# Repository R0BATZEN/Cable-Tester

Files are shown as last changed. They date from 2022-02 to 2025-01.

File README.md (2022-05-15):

# Cable Tester
Inspired by [brodafins](https://www.youtube.com/channel/UCYWdkH3cT7uKhssbFg7uHtw) cable tester I decided to add my own twist to it and make a modified version.

If you would like to check out the original project you should watch his [youtube video](https://www.youtube.com/watch?v=r3Qzw2hiL2Y) and see how he built his unit.
His code can be found in the `brodafin` folder of this repository.

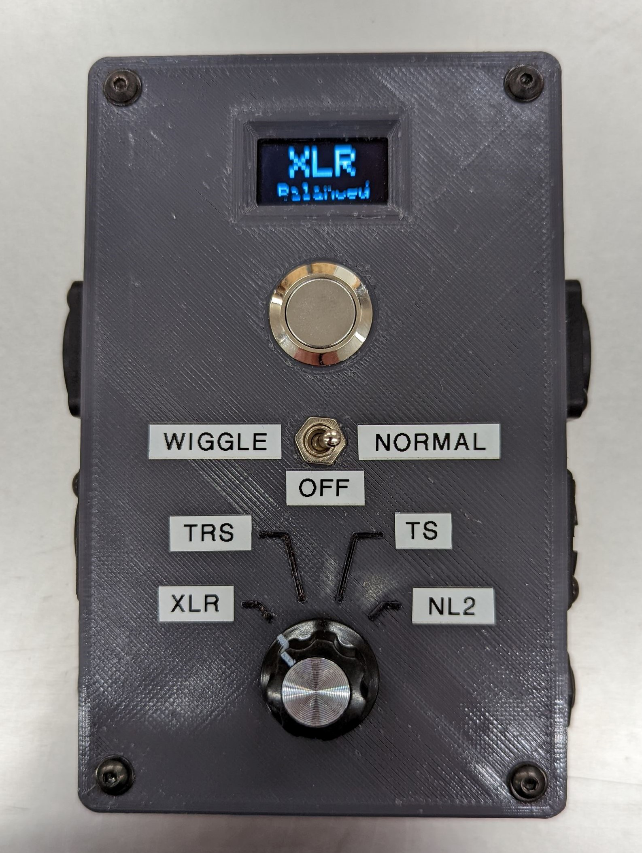
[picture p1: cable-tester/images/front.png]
||||
|-|-|-|
|Front view|Input Side|Output Side|

Besides XLR and 1/4" cables I also use SpeakOn (PA speaker) Cables.
So I added the option to also test those cables (NL2 and NL4 only, I don't use NL8).

## Circuit Design
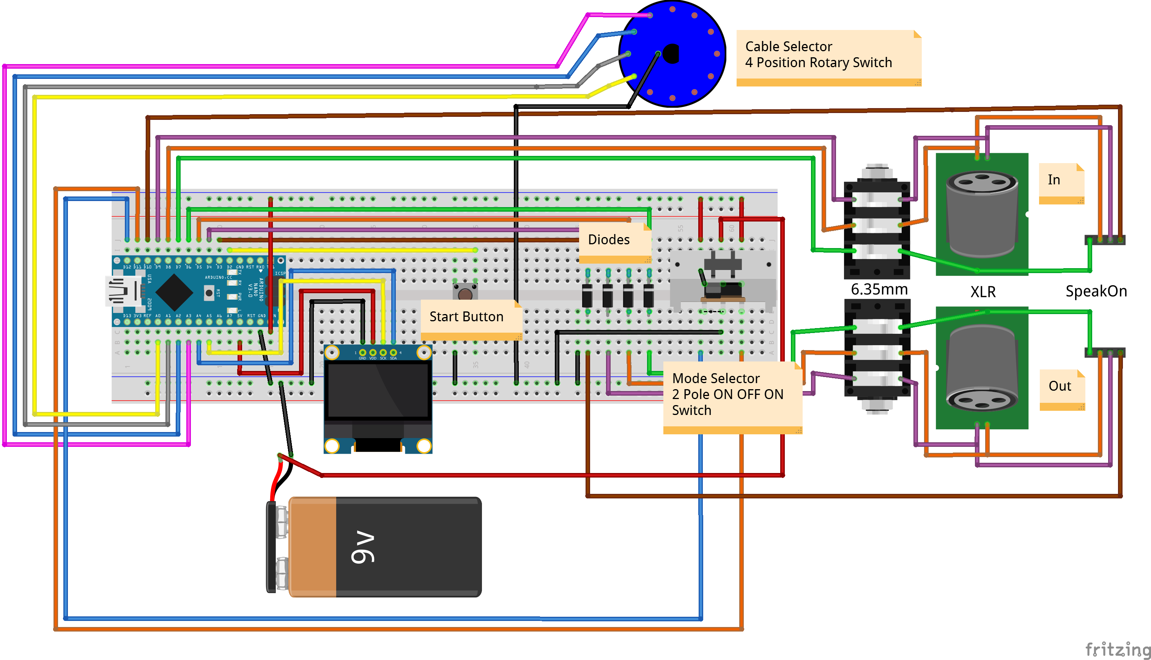
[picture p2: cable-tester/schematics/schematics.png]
schematic

Take a look at the [fritzing file](cable-tester/schematics/schematics.fzz) if you need more details.

## 3D Printed Case
Feel free to download and print my case. Just make sure that your inputs / buttons match mine so that the holes will fit.
In case you want to modify it before printing, I have included my source files.

## Installing the Code
You should be able to just download my source code and flash it to your Arduino (Nano).
If you would like to use different pins for each in/output, the corresponding variables are all at the top of the file.

## Using the Tester
- First decide which mode (wiggle or normal) you would like to use. Flip the switch accordingly and wait ~2 seconds for everything to start up.
- Then connect your cable and select to proper setting using the rotary switch.
- After pressing the start button you will get your results. Either after the "wiggle period" is over or directly after testing.
- First a brief `FAIL` or `PASS` message will appear, after which the detailed test report will be displayed until you press the start button again.
- As an example, here's what a `passing` XLR cable will show:

| |2|3|1|/|
|-|-|-|-|-|
|2|X|O|O|O|
|3|O|X|O|O|
|1|O|O|X|O|
|/|O|O|O|O|

- The rows correspond to each pin on the output and the columns mark the inputs on the other side of the device.
`X` denotes a connection between the two pins and `O` means no connection.
- Take a look at my [cheat sheet](cable-tester/cheat_sheets/cheat_sheet.md) to see how each cable is expected to be wired up.

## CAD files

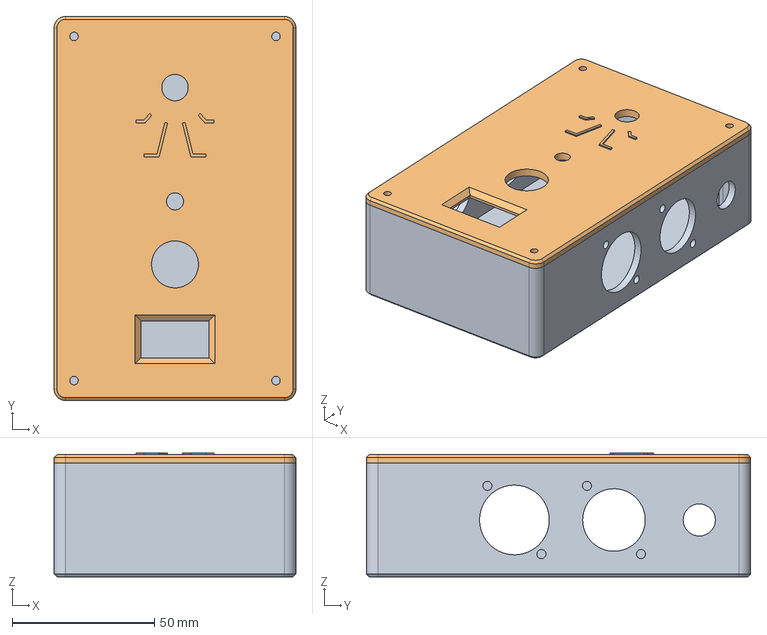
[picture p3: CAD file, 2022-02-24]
cable-tester/3d files/CableTester.step
85.0 x 135.0 x 43.5 mm

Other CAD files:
cable-tester/3d files/CableTester.3mf
cable-tester/3d files/CableTester.f3d

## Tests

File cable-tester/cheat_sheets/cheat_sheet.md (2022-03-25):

# Pins on each cable
And how they are connected to each other in this tester:

|XLR|TRS|TS|SpeakOn|
|-|-|-|-|
|2|T|T|1+|
|3|R|S|1-|
|1|S|S|2+|
|/|/|/|2-|

# Expected test results

## XLR (Balanced)

| |2|3|1|/|
|-|-|-|-|-|
|2|X|O|O|O|
|3|O|X|O|O|
|1|O|O|X|O|
|/|O|O|O|O|

## 1/4" TRS (Stereo / Balanced)

| |T|R|S|/|
|-|-|-|-|-|
|T|X|O|O|O|
|R|O|X|O|O|
|S|O|O|X|O|
|/|O|O|O|O|

## 1/4" TS (Mono / Unbalanced)

| |T|R|S|/|
|-|-|-|-|-|
|T|X|O|O|O|
|R|O|X|X|O|
|S|O|X|X|O|
|/|O|O|O|O|

## SpeakOn (NL2)

| |1+|1-|/|/|
|-|-|-|-|-|
|1+|X|O|O|O|
|1-|O|X|O|O|
|/|O|O|O|O|
|/|O|O|O|O|

## SpeakOn (NL4)

| |1+|1-|2+|2-|
|-|-|-|-|-|
|1+|X|O|O|O|
|1-|O|X|O|O|
|2+|O|O|X|O|
|2-|O|O|O|X|

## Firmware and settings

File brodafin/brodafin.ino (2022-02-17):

//Musicians Cable Tester (SCT)  20210822 by Brodafin
#include <SPI.h>
#include <Wire.h>
#include <Adafruit_GFX.h>
#include <Adafruit_SSD1306.h>
#define OLED_RESET 4
Adafruit_SSD1306 display(OLED_RESET);
int Pass = 0;
int sensTRS = 10;
int sensTS = 11;
int sensMode = 12;
int tip1 = 4;
int ring1 = 5;
int sleeve1 = 6;
int tip2 = 7;
int ring2 = 8;
int sleeve2 = 9;
int TRS = 0;
volatile int testPressed = 0;
int cableType = 0;
int muX = 0;
int TmaskXLRTRS[ 3 ][ 3 ] = { {0, 1, 1}, {1, 0, 1}, {1, 1, 0} } ;
int TmaskTS[3][3] = { {0, 1, 1}, {1, 0, 0}, {1, 0, 0} };
int Tread[ 3 ][ 3 ] = { {0, 0, 0}, {0, 0, 0}, {0, 0, 0} } ;
String openStatus = "Open: T,R,S";
String shortStatus = "Shrt:TRTSRS";
char iDent[7] = {'0', '2', '3', '1', 'T', 'R', 'S',};
unsigned long timeout = 10000;
unsigned long interVal = 0;
void setup()   {
  Serial.begin(9600);
  display.begin(SSD1306_SWITCHCAPVCC, 0x3C);
  display.clearDisplay();
  display.setTextWrap(false);
  display.setTextSize(2);
  display.setTextColor(WHITE);
  display.display();
  attachInterrupt(0, testButtonPressed, HIGH);
  pinMode(sensTRS, INPUT_PULLUP);
  pinMode(sensTS, INPUT_PULLUP);
  pinMode(sensMode, INPUT_PULLUP);
  pinMode(tip1, OUTPUT);
  pinMode(ring1, OUTPUT);
  pinMode(sleeve1, OUTPUT);
  pinMode(tip2, INPUT_PULLUP);
  pinMode(ring2, INPUT_PULLUP);
  pinMode(sleeve2, INPUT_PULLUP);
}
void loop() {
  display.setTextSize(2);
  if (digitalRead(sensTRS) == HIGH && digitalRead(sensTS) == HIGH) {
    cableType = 1; muX = 1;
    display.clearDisplay();
    display.setCursor(14, 10); display.println("XLR Cable");
    display.display();
  }
  if (digitalRead(sensTS) == LOW) {
    cableType = 2;  muX = 4;
    display.clearDisplay(); display.setCursor(8, 10);
    display.println("Mono Cable");
    display.display();
  }
  if (digitalRead(sensTRS) == LOW) {
    cableType = 3; muX = 4;
    display.clearDisplay(); display.setCursor(0, 10);
    display.println("StereoCable");
    display.display();
  }
  if (testPressed == 1) {
    delay(50); testPressed = 0;
    if (digitalRead(sensMode) == 1 ) {
      clearStatusVars(); doWiggleTest(); testPressed = 0; checkResults();
    } else {
      doNormalTest();
      testPressed = 0;
      checkResults();
    }
  }
}
void doNormalTest() {
  display.clearDisplay(); display.setTextSize(3);
  display.setCursor(0, 8); display.println("TESTING");
  display.display();
  delay(100);
  pinMode(sleeve1, OUTPUT);
  digitalWrite(tip1, LOW);
  digitalWrite(ring1, HIGH);
  digitalWrite(sleeve1, HIGH); delay(1);
  Tread[0][0] = digitalRead(tip2);
  Tread[0][1] = digitalRead(ring2);
  Tread[0][2] = digitalRead(sleeve2); digitalWrite(tip1, HIGH);
  digitalWrite(ring1, LOW); delay(1);
  Tread[1][0] = digitalRead(tip2);
  Tread[1][1] = digitalRead(ring2);
  Tread[1][2] = digitalRead(sleeve2); digitalWrite(ring1, HIGH);
  digitalWrite(sleeve1, LOW); delay(1);
  Tread[2][0] = digitalRead(tip2);
  Tread[2][1] = digitalRead(ring2);
  Tread[2][2] = digitalRead(sleeve2); digitalWrite(sleeve1, HIGH);
}
void checkResults() {
  Pass = 1;
  if (digitalRead(sensMode) != 1 ) {
    clearStatusVars();
  }
  if (cableType == 2) {
    for (int i = 0; i < 3; i++) {
      for (int j = 0; j < 3; j++) {
        if (Tread[i][j] != TmaskTS[i][j]) {
          Pass = 0;
          if (Tread[i][j] > TmaskTS[i][j]) {
            openStatus.setCharAt(i + 1 + 5, iDent[i + muX]);
          }
        }
      }
    }
    if (Tread[0][2] == 0 && Tread[2][0] == 0) {
      shortStatus.setCharAt(7, iDent[muX]);
      shortStatus.setCharAt(8, iDent[muX + 2]);
    }
  }  else {
    for (int i = 0; i < 3; i++) {
      for (int j = 0; j < 3; j++) {
        if (Tread[i][j] != TmaskXLRTRS[i][j]) {
          Pass = 0;
          if (Tread[i][j] > TmaskXLRTRS[i][j]) {
            openStatus.setCharAt(i * 2 + 5, iDent[i + muX]);
          }
        }
      }
    }
    if (Tread[0][1] == 0 || Tread[1][0] == 0) {
      shortStatus.setCharAt(5, iDent[muX]);
      shortStatus.setCharAt(6, iDent[muX + 1]);
    }
    if (Tread[0][2] == 0 || Tread[2][0] == 0) {
      shortStatus.setCharAt(7, iDent[muX]);
      shortStatus.setCharAt(8, iDent[muX + 2]);
    }
    if (Tread[1][2] == 0 || Tread[2][1] == 0) {
      shortStatus.setCharAt(9, iDent[muX + 1]);
      shortStatus.setCharAt(10, iDent[muX + 2]);
    }
  }
  display.clearDisplay();
  display.setTextSize(3);
  display.setCursor(30, 8);
  if (Pass == 1) {
    display.print("PASS");
    display.display();
    delay(1000);
  } else {
    display.print("FAIL");
    display.display();
    delay(1000);
    showResults();
  }
}
void doWiggleTest() {
  display.clearDisplay();
  display.setTextSize(3);
  display.setCursor(0, 8);
  display.println("WIGGLE.");
  display.display();
  Pass = 1; testPressed = 0;
  interVal = millis();
  while (Pass == 1 && (millis() - interVal) < timeout) {
    pinMode(sleeve1, OUTPUT);
    digitalWrite(tip1, LOW);
    digitalWrite(ring1, HIGH);
    digitalWrite(sleeve1, HIGH);
    delay(1);
    Tread[0][0] = digitalRead(tip2);
    Tread[0][1] = digitalRead(ring2);
    Tread[0][2] = digitalRead(sleeve2);
    digitalWrite(tip1, HIGH);
    digitalWrite(ring1, LOW);
    delay(1);
    Tread[1][0] = digitalRead(tip2);
    Tread[1][1] = digitalRead(ring2);
    Tread[1][2] = digitalRead(sleeve2);
    digitalWrite(ring1, HIGH);
    digitalWrite(sleeve1, LOW);
    delay(1);
    Tread[2][0] = digitalRead(tip2);
    Tread[2][1] = digitalRead(ring2);
    Tread[2][2] = digitalRead(sleeve2);
    digitalWrite(sleeve1, HIGH);

    if (cableType == 2) {
      for (int i = 0; i < 3; i++) {
        for (int j = 0; j < 3; j++) {
          if (Tread[i][j] != TmaskTS[i][j]) {
            Pass = 0;
          }
        }
      }
    }  else {
      for (int i = 0; i < 3; i++) {
        if (Pass == 0) {
          continue;
        }
        for (int j = 0; j < 3; j++) {
          if (Pass == 0) {
            continue;
          }
          if (Tread[i][j] != TmaskXLRTRS[i][j]) {
            Pass = 0;
          }
        }
      }
    }
  }
}
void clearStatusVars() {
  for (int i = 5; i < 11; i++) {
    openStatus.setCharAt(i, 32);
  }
  for (int i = 5; i < 11; i++) {
    shortStatus.setCharAt(i, 32);
  }
}
void showResults() {
  testPressed = 0;
  display.clearDisplay();
  display.setTextSize(2);
  display.setCursor(0, 0);
  display.print(openStatus);
  display.setCursor(0, 18);
  display.print(shortStatus);
  display.display();
  while (testPressed != 1) {
    delay(10);
  }
  display.clearDisplay();
  display.display();
  delay(200);
  testPressed = 0;
}
void testButtonPressed() {
  testPressed = 1;
  delay(500);
}

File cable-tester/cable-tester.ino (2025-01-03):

#include <SPI.h>
#include <Wire.h>
#include <Adafruit_GFX.h>
#include <Adafruit_SSD1306.h>

#define SCREEN_WIDTH 128 // OLED display width, in pixels
#define SCREEN_HEIGHT 64 // OLED display height, in pixels

#define OLED_RESET     -1 // Reset pin # (or -1 if sharing Arduino reset pin)

#define SCREEN_ADDRESS 0x3D ///< See datasheet for Address; 0x3D for 128x64, 0x3C for 128x32
Adafruit_SSD1306 display(SCREEN_WIDTH, SCREEN_HEIGHT, &Wire, OLED_RESET);

const long interval = 10000;           // interval at which to test wiggle mode (milliseconds)
unsigned long previousMillis = 0;

const int OUT1 = 6; // TIP / 2 / 1+
const int OUT2 = 5; // RING / 3 / 1-
const int OUT3 = 4; // SLEEVE / 1 / 2+
const int OUT4 = 3; // 2-

const int IN1 = 7; // TIP / 2 / 1+
const int IN2 = 8; // RING / 3 / 1-
const int IN3 = 9; // SLEEVE / 1 / 2+
const int IN4 = 10; // 2-

const int START_BUTTON = 2;

const int WIGGLE_SWITCH = 11;
const int NORMAL_SWITCH = 12;

const int MONO_SWITCH = A1;
const int NL2_SWITCH = A2;
const int STEREO_SWITCH = A0;

const int XLR[4][4] = { {0, 1, 1, 1},
                        {1, 0, 1, 1},
                        {1, 1, 0, 1} ,
                        {1, 1, 1, 1 } };

const int STEREO[4][4] = { {0, 1, 1, 1},
                           {1, 0, 1, 1},
                           {1, 1, 0, 1},
                           {1, 1, 1, 1} };

const int MONO[4][4] = { {0, 1, 1, 1},
                         {1, 0, 0, 1},
                         {1, 0, 0, 1},
                         {1, 1, 1, 1} };

const int NL2[4][4] = { {0, 1, 1, 1},
                        {1, 0, 1, 1},
                        {1, 1, 1, 1},
                        {1, 1, 1, 1} };

const int NL4[4][4] = { {0, 1, 1, 1},
                        {1, 0, 1, 1},
                        {1, 1, 0, 1},
                        {1, 1, 1, 0} };

char XLR_pins[3][2] = { "3", "2", "1" };
char MONO_pins[3][2] = { "T", "R", "S" };
char NL2_pins[2][3] = { "+1", "-1" };
char NL4_pins[4][3] = { "1+", "1-", "2+", "2-" };

int operatingMode; // 0 = wiggle, 1 = normal
int cableType;    // 3 = XLR, 2 = TS , 4 = TRS, 5 = NL2

int inputs[] = { IN1, IN2, IN3, IN4, WIGGLE_SWITCH, NORMAL_SWITCH, MONO_SWITCH, STEREO_SWITCH, NL2_SWITCH, START_BUTTON};
int outputs[] = {OUT1, OUT2, OUT3, OUT4};

int pass = 1;

//========================================================================================================
//=== GET OPERATING MODE (WIGGLE OR NORMAL) ==============================================================
//========================================================================================================
int getOperatingMode() {

    int mode = 1;

    //Serial.print("Wiggle: ");
    //Serial.println(digitalRead(WIGGLE_SWITCH));
    //Serial.print("Normal: ");
    //Serial.println(digitalRead(NORMAL_SWITCH));

    if (!digitalRead(WIGGLE_SWITCH)) {
        mode = 0;
    } else if (!digitalRead(NORMAL_SWITCH)) {
        mode = 1;
    }
    //Serial.print("Mode: ");
    //Serial.println(mode);
    return mode;
}

//========================================================================================================
//=== GET CABLE TYPE (MONO, XLR/STEREO, NL2, NL4) =========================================================
//========================================================================================================
int getCableType() {

    int cable;

    if (!digitalRead(MONO_SWITCH)) { //TS
        cable = 2;
    } else if (!digitalRead(STEREO_SWITCH)) { //TRS
        cable = 4;
    } else if (!digitalRead(NL2_SWITCH)){ //NL2
        cable = 5;
    }else {   //XLR
        cable = 3;
    }

    return cable;
}



//====================================================================================
//=== SETUP ==========================================================================
//====================================================================================
void setup() {

    Serial.begin(9600);
    //Serial.println("Starting System");
    //Serial.println("---------------------");
    //Serial.println("Test");

    display.begin(SSD1306_SWITCHCAPVCC, 0x3C);
    display.clearDisplay();
    display.setTextWrap(false);
    display.setTextSize(3);
    display.setTextColor(WHITE);
    display.display();

    //=== set the pins as Inputs =======================================================
    for (int i = 0; i < (sizeof(inputs) / sizeof(inputs[0])); i++) {
        pinMode(inputs[i], INPUT_PULLUP);
    }

    //=== set the pins as output: =======================================================
    for (int i = 0; i < (sizeof(outputs) / sizeof(outputs[0])); i++) {
        pinMode(outputs[i], OUTPUT);
    }

    //=== get operating Mode ============================================================
    operatingMode = getOperatingMode();
}

void loop() {

    cableType = getCableType();

    //Serial.print("Cable: ");
    //Serial.println(cableType);

    display.clearDisplay();
    display.setTextSize(4);

    if (cableType == 2) {
        display.setCursor(40, 8);
        display.println("TS");
        display.setTextSize(2);
        display.setCursor(5, 47);
        display.println("Unbalanced");
    } else if ( cableType == 3) {
        display.setCursor(30, 8);
        display.println("XLR");
        display.setTextSize(2);
        display.setCursor(18, 47);
        display.println("Balanced");
    } else if (cableType == 4) {
        display.setCursor(30, 8);
        display.println("TRS");
        display.setTextSize(2);
        display.setCursor(18, 47);
        display.println("Balanced");
    } else if (cableType == 5) {
        display.setTextSize(3);
        display.setCursor(1, 10);
        display.println("SpeakOn");
        display.setTextSize(2);
        display.setCursor(45, 47);
        display.println("NL2");
    }

    display.display();

    if (!digitalRead(START_BUTTON)) {
        startTest();
        delay(200);
    }
}

void startTest() {

    //Serial.print("Starting Test, Mode: ");
    //Serial.println(operatingMode);

    cableType = getCableType();

    if (operatingMode == 0) {
        testWiggle();
    } else if (operatingMode == 1) {
        testNormal();
    }
}
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

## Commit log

2022-02-20 Trying out failure descriptions
    [cable-tester.ino]
2022-02-20 Add schematics file
    [schematics.fzz]
2022-02-21 More experiments for failure descriptions
    [cable-tester.ino]
2022-02-21 Change circuit design to use rotary switch
    [schematics.fzz]
2022-02-21 Cleanup cable runs
    [schematics.fzz]
2022-02-21 Reverse diode polarity
    [schematics.fzz]
2022-02-21 Clean up
    [schematics.fzz]
2022-02-22 Change SpeakOn pin labels
2022-02-22 Add labels for input and output
    [schematics.fzz]
2022-02-24 Finalize circuit design
    [schematics.fzz]
2022-02-24 Add circuit image for readme file
    [schematics.fzz]
2022-02-24 Fix filename spelling (case sensitive)
2022-02-24 Add 3d files for case
    [CableTester.3mf, CableTester.f3d, CableTester.step]
2022-03-04 Change cable type designation
2025-01-03 Fix missing comma (#1)
    Closes #1
    [cable-tester.ino]
